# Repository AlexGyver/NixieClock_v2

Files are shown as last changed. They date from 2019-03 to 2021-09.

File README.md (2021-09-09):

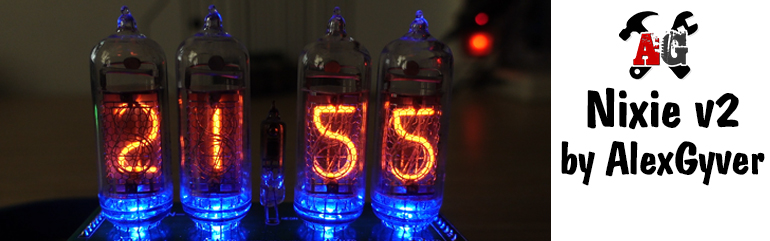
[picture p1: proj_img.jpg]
PROJECT_PHOTO

# Часы на газоразрядных индикаторах и Arduino
* [Описание проекта](#chapter-0)
* [Папки проекта](#chapter-1)
* [Схемы подключения](#chapter-2)
* [Материалы и компоненты](#chapter-3)
* [Как скачать и прошить](#chapter-4)
* [FAQ](#chapter-5)
* [Полезная информация](#chapter-6)
AlexGyver YouTube (https://www.youtube.com/channel/UCgtAOyEQdAyjvm9ATCi_Aig?sub_confirmation=1)

## Описание проекта
Часы на советских газоразрядных индикаторах под управлением платформы Arduino, версия 2. 
Страница проекта на сайте: https://alexgyver.ru/nixieclock_v2/

Решил я сделать максимально простой и доступный проект часов на газоразрядных индикаторах и Arduino! Односторонняя плата, выводные компоненты, никакой жести!

Платы:
- Габариты платы меньше 100х100мм, то есть заказать 10 таких плат у китайцев будет стоить $2 без учёта доставки
- Плата односторонняя, её без проблем можно сделать классическим ЛУТом!
- Все компоненты – выводные, припаяет даже новичок
- Количество компонентов сведено к минимуму!
- На данный момент в проекте есть платы под индикаторы ИН-12 и ИН-14, возможно будут сделаны и другие
- Система состоит из двух плат: нижней (вся управляющая электроника) и верхней (лампы и светодиоды подсветки)
- Нижних плат два варианта: обычная (4 оптопары, точка – светодиод) и с дополнительной оптопарой под неоновую точку (5 оптопар, точка – неонка)
- У плат ИН-14, ИН-12, ИН-12_перевертыш нижняя часть одинаковая! Части плат взаимозаменяемы. Нижняя плата отличается только у ИН-14_неон  

Хардварные фишки:
- Сердце платы – полноразмерная Arduino NANO, это означает простую сборку и прошивку
- Питание всей схемы – 5 Вольт
- Генератор высокого напряжения раскачивается ШИМ каналом Arduino
- Напряжение генератора подстраивается резистором с крутилкой
- Время задаёт RTC DS3231
- 3 кнопки для настройки времени и будильника
- Пищалка для будильника
- Подсветка ламп индикаторов
- Проект основан на плате Железнякова Андрея. Спасибо! Ссылка на проект: https://goo.gl/xTVQWP  

Софтварные фишки:
- “Перебор” цифр, не дающий индикаторам окисляться
- Режим будильника
- Плавное изменение яркости точки и подсветки (эффект “дыхания”)
	+ Расширенные настройки плавности дыхания
- Настройка яркости цифр, “точки” и подсветки ламп
	+ Два режима яркости от времени суток
- Разные режимы переключения индикаторов
	+ Плавное угасание/разгарание
	+ Перебор цифр
	+ Перебор катодов

## Папки
**ВНИМАНИЕ! Если это твой первый опыт работы с Arduino, читай [инструкцию](#chapter-4)**
- **libraries** - библиотеки проекта. Заменить имеющиеся версии (в этом проекте внешних библиотек нет)
- **firmware** - прошивки для Arduino
- **schemes** - схемы подключения компонентов

## Схемы
Платы:
- IN-14 - для индикаторов ИН-14 со светодиодной точкой https://easyeda.com/editor#id=1d7c359f88254c9d9c7ce9de914bd4c5
- IN-14_mini_neon_dot - для IN-14 с точкой - индикатором (+1 оптопара и резистор) https://easyeda.com/editor#id=be6c3cd8d42a414b8a8e5b9bdd0401bf
- IN-12 - для IN-12, цифры перевёрнуты вверх ногами (если смотреть на плату) https://easyeda.com/editor#id=1d7c359f88254c9d9c7ce9de914bd4c5
- IN-12_turned - для IN-12, цифры повёрнуты правильно https://easyeda.com/editor#id=aea22745380847b5beeca679820e7565  

Открыв плату по ссылке, её можно экспортировать в PDF, PNG или Altium (иконка папки слева сверху/экспорт) для изготовления ЛУТом или другими способами!  
При заказе плат у китайцев не забудьте указать в комментарии "Please make V-cut along middle thick horizontal outline" для надреза платы по средней линии  
**Гербер файлы уже есть в архиве!**
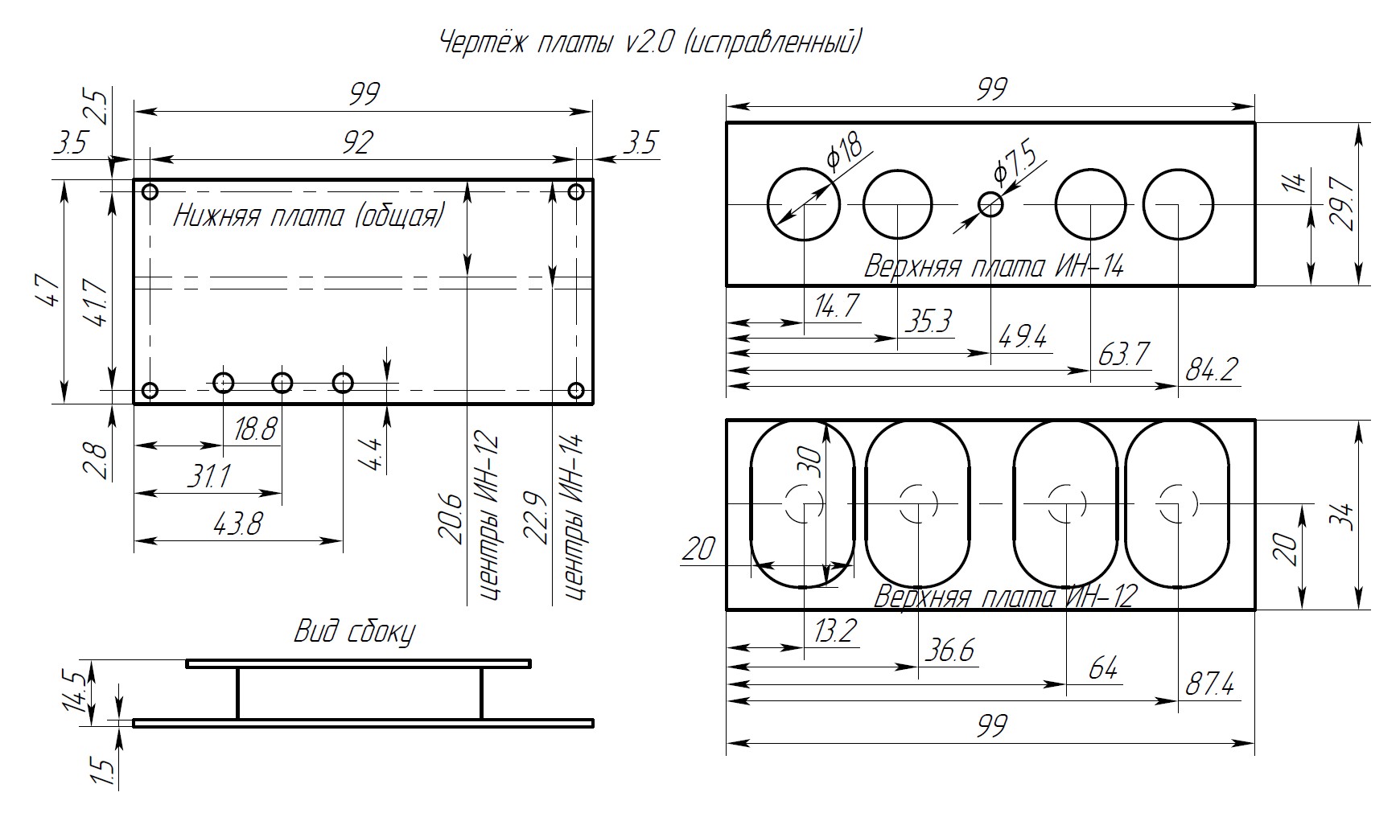
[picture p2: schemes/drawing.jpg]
SCHEME


## Материалы и компоненты
### Ссылки оставлены на магазины, с которых я закупаюсь уже не один год
- Arduino NANO Rev3.0 https://ali.ski/670JrC  https://ali.ski/_7IUJ
- RTC DS3231 https://ali.ski/gOYYG0
- Пищалка https://ali.ski/8LEYlE
- Гнёзда на плату https://www.chipdip.ru/product/pbs-40
- Рейка штыревая https://www.chipdip.ru/product/pls-40
- Конденсатор электролитический 4,7 мкФ 350V	https://www.chipdip.ru/product0/33635
- Резистор подстроечный 470 кОм (можно 500 кОм)	https://www.chipdip.ru/product/3362p-1-504
- Индуктивность 220 мкГн (uH)	https://www.chipdip.ru/product/ec24-221k
- Диод HER106	https://www.chipdip.ru/product/her106
- Транзистор IRF840PBF	https://www.chipdip.ru/product/irf840
- Оптопара TLP627(F) DIP-4	https://www.chipdip.ru/product/tlp627
- Дешифратор К155ИД1	https://www.chipdip.ru/product/k155id1
- Резисторы 0,25 Вт для версии ИН12/ИН14 со светодиодной точкой
	- 150 Ом
	- 470 Ом
	- 10 кОм	
	- 100 Ом - 3шт	
- Резисторы 0,25 Вт для версии ИН14 с неоновой точкой
	- 200 кОм
	- 470 Ом
	- 10 кОм	
	- 100 Ом - 3шт

## Вам скорее всего пригодится
* [Всё для пайки (паяльники и примочки)](http://alexgyver.ru/all-for-soldering/)
* [Недорогие инструменты](http://alexgyver.ru/my_instruments/)
* [Все существующие модули и сенсоры Arduino](http://alexgyver.ru/arduino_shop/)
* [Электронные компоненты](http://alexgyver.ru/electronics/)
* [Аккумуляторы и зарядные модули](http://alexgyver.ru/18650/)

## Как скачать и прошить
* [Первые шаги с Arduino](http://alexgyver.ru/arduino-first/) - ультра подробная статья по началу работы с Ардуино, ознакомиться первым делом!
* Скачать архив с проектом
> На главной странице проекта (где ты читаешь этот текст) вверху справа зелёная кнопка **Clone or download**, вот её жми, там будет **Download ZIP**
* Установить библиотеки в  
`C:\Program Files (x86)\Arduino\libraries\` (Windows x64)  
`C:\Program Files\Arduino\libraries\` (Windows x86)
* **Подключить внешнее питание 5 Вольт**
* Подключить Ардуино к компьютеру
* Запустить файл прошивки (который имеет расширение .ino)
* Настроить IDE (COM порт, модель Arduino, как в статье выше)
* Настроить что нужно по проекту
* Нажать загрузить
* Пользоваться  

## Настройки в коде

## FAQ
### Основные вопросы
В: Как скачать с этого грёбаного сайта?  
О: На главной странице проекта (где ты читаешь этот текст) вверху справа зелёная кнопка **Clone or download**, вот её жми, там будет **Download ZIP**

В: Скачался какой то файл .zip, куда его теперь?  
О: Это архив. Можно открыть стандартными средствами Windows, но думаю у всех на компьютере установлен WinRAR, архив нужно правой кнопкой и извлечь.

В: Я совсем новичок! Что мне делать с Ардуиной, где взять все программы?  
О: Читай и смотри видос http://alexgyver.ru/arduino-first/

В: Вылетает ошибка загрузки / компиляции!
О: Читай тут: https://alexgyver.ru/arduino-first/#step-5

В: Сколько стоит?  
О: Ничего не продаю.

### Вопросы по этому проекту

## Полезная информация
* [Мой сайт](http://alexgyver.ru/)
* [Основной YouTube канал](https://www.youtube.com/channel/UCgtAOyEQdAyjvm9ATCi_Aig?sub_confirmation=1)
* [YouTube канал про Arduino](https://www.youtube.com/channel/UC4axiS76D784-ofoTdo5zOA?sub_confirmation=1)
* [Мои видеоуроки по пайке](https://www.youtube.com/playlist?list=PLOT_HeyBraBuMIwfSYu7kCKXxQGsUKcqR)
* [Мои видеоуроки по Arduino](http://alexgyver.ru/arduino_lessons/)

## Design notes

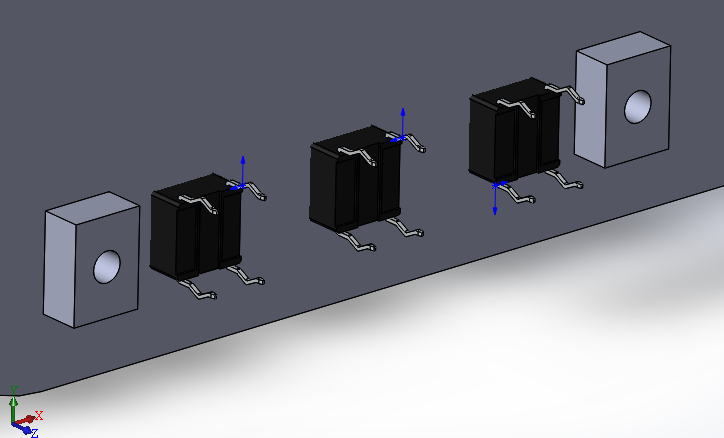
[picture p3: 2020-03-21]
case/IN-12_Max/Кнопки1.png

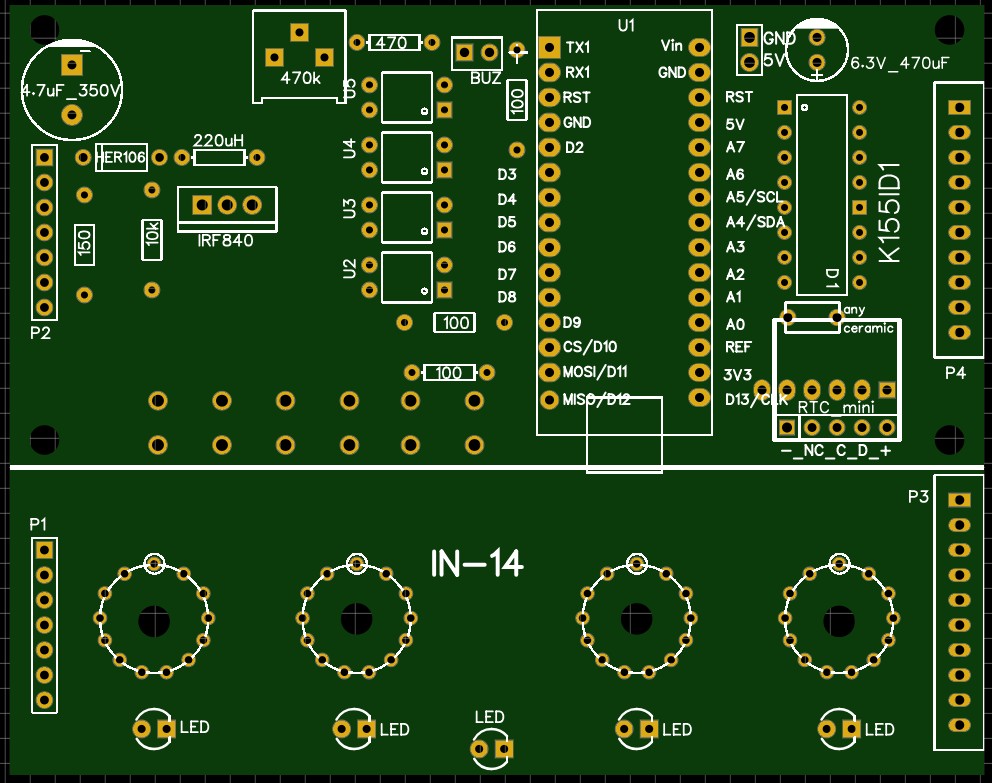
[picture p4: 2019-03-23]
schemes/IN-14.jpg

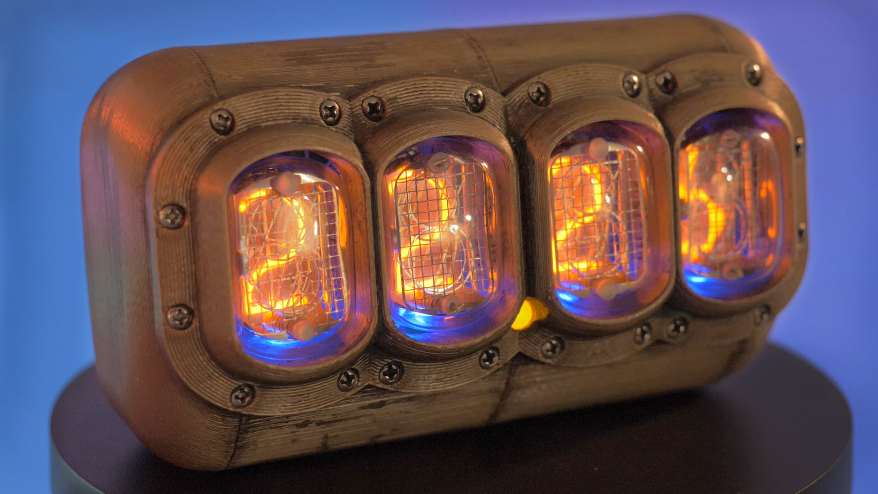
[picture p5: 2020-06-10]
case/IN-12_Gyver/photo.jpg

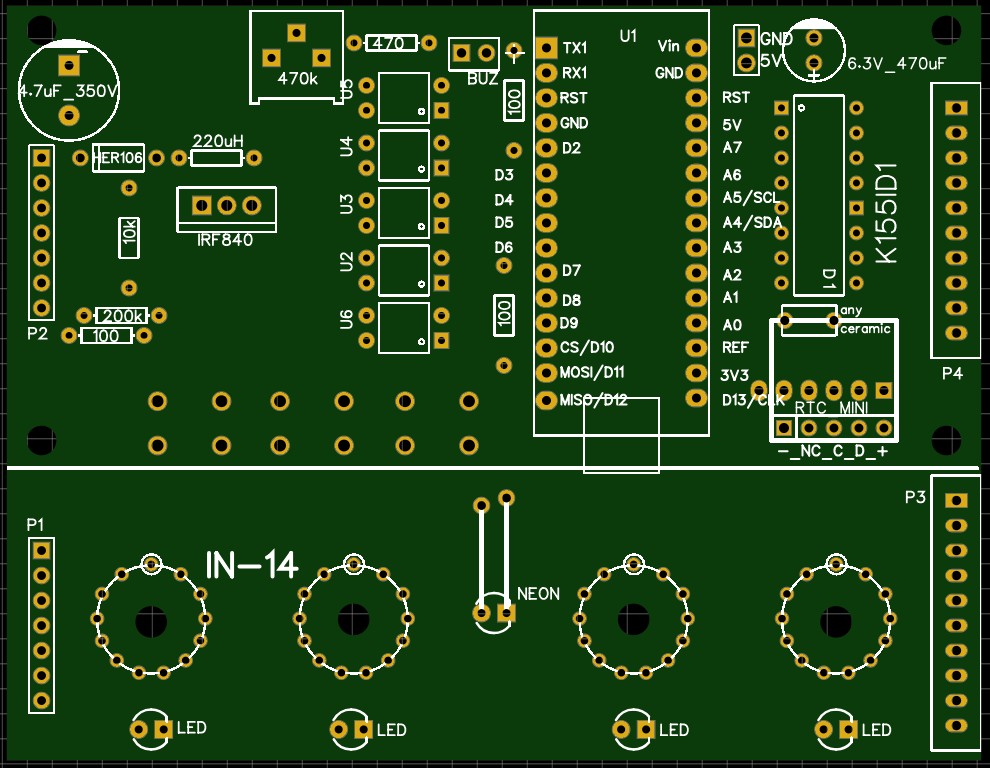
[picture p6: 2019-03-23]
schemes/IN-14_NEON.jpg

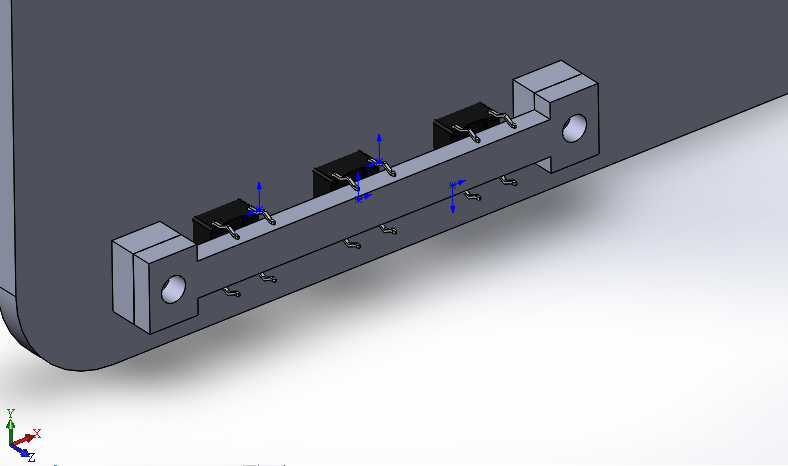
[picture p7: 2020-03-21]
case/IN-12_Max/Кнопки2.png

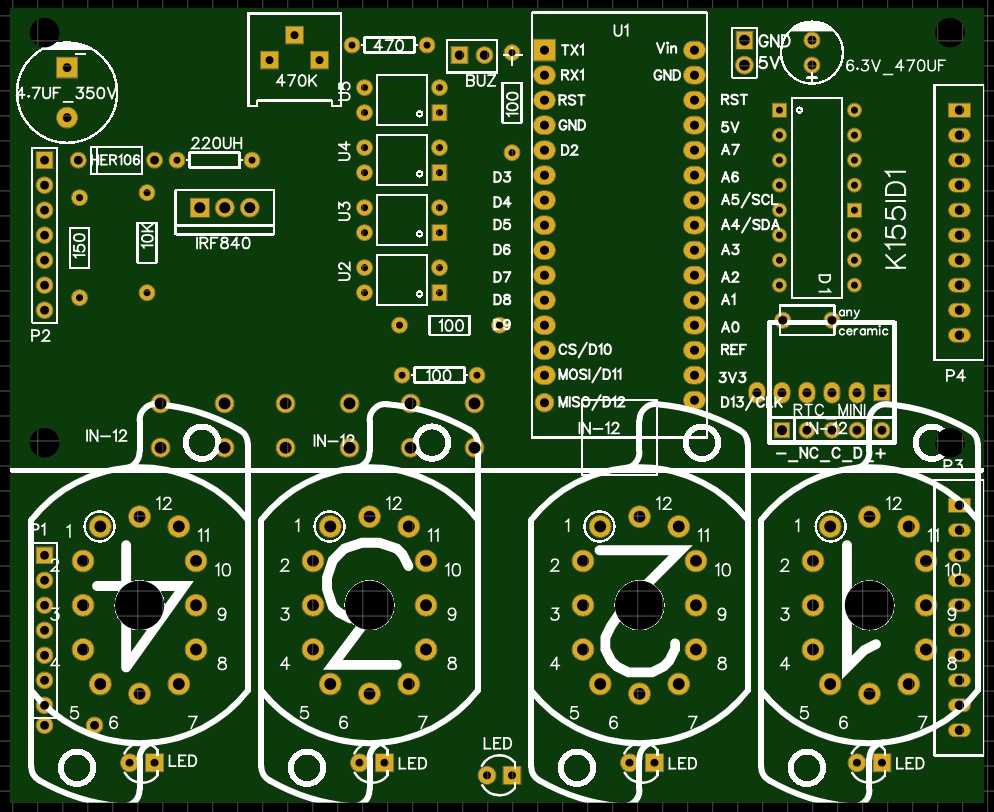
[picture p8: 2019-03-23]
schemes/IN-12.jpg

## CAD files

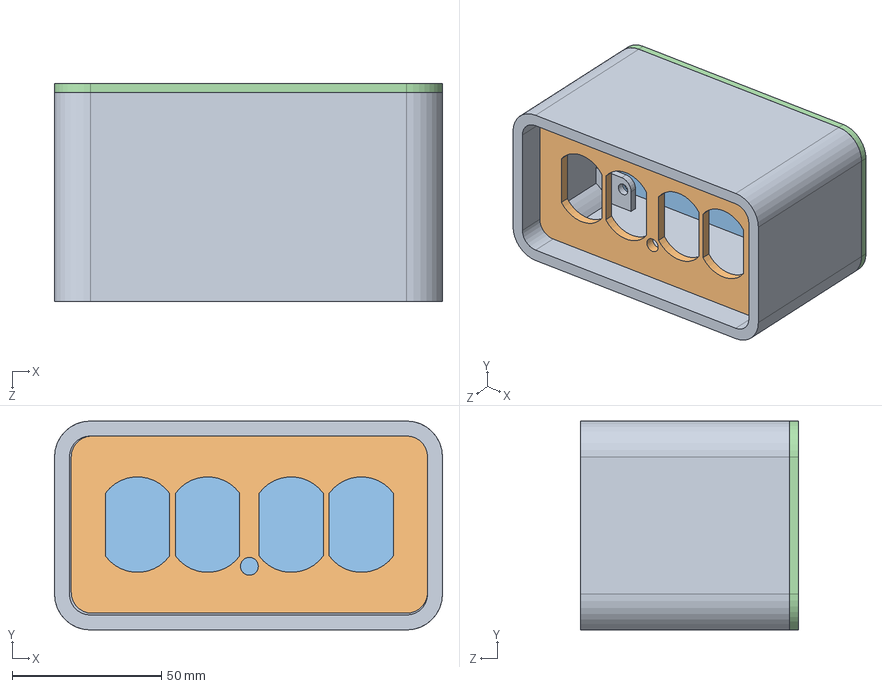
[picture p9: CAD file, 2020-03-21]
case/IN-12_Max/Исходники/Сборка ГРИ.SLDASM
130.0 x 70.0 x 73.0 mm
корпус
панель
плата
крышка
крепление кнопок

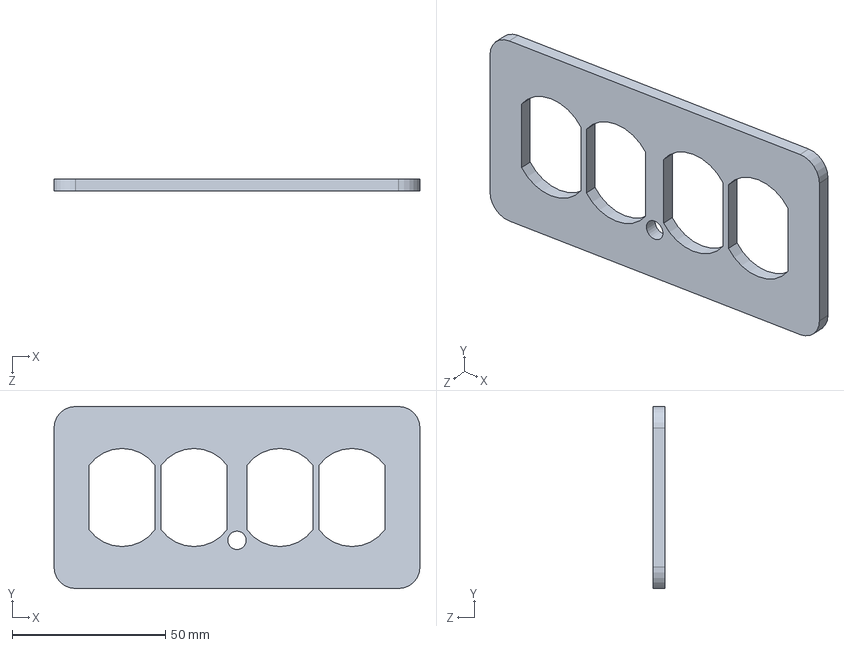
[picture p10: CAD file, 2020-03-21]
case/IN-12_Max/Исходники/панель.SLDPRT
119.4 x 59.4 x 4.00 mm

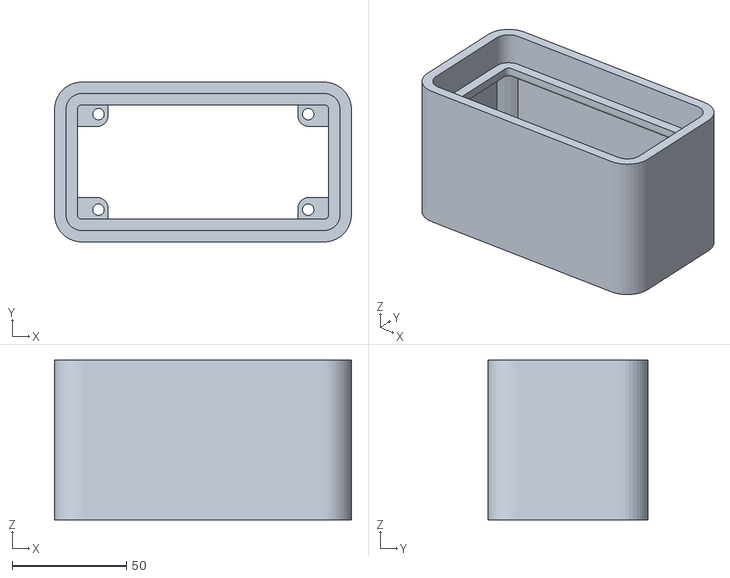
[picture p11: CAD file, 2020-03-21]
case/IN-12_Max/Файлы для печати/корпус.STL
130.0 x 70.0 x 70.0

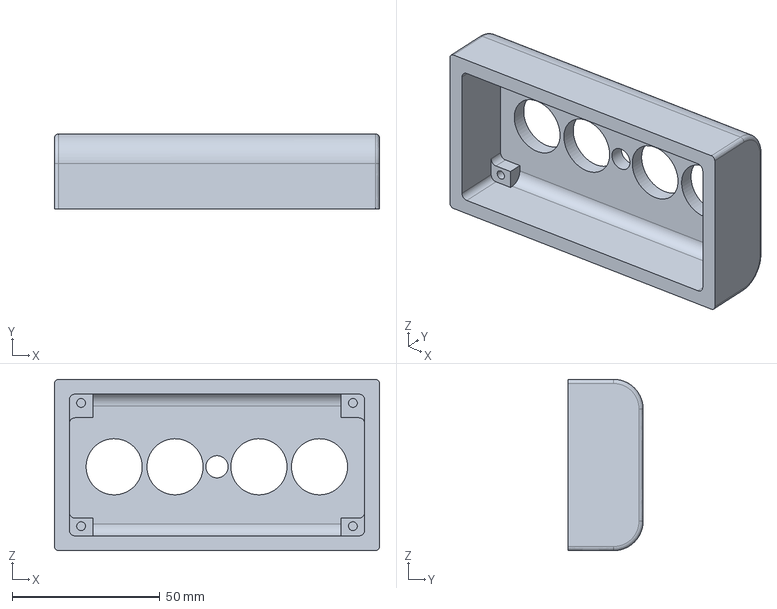
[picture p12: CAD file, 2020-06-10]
case/IN-14_Gyver/step/body.step
110.0 x 25.5 x 58.0 mm

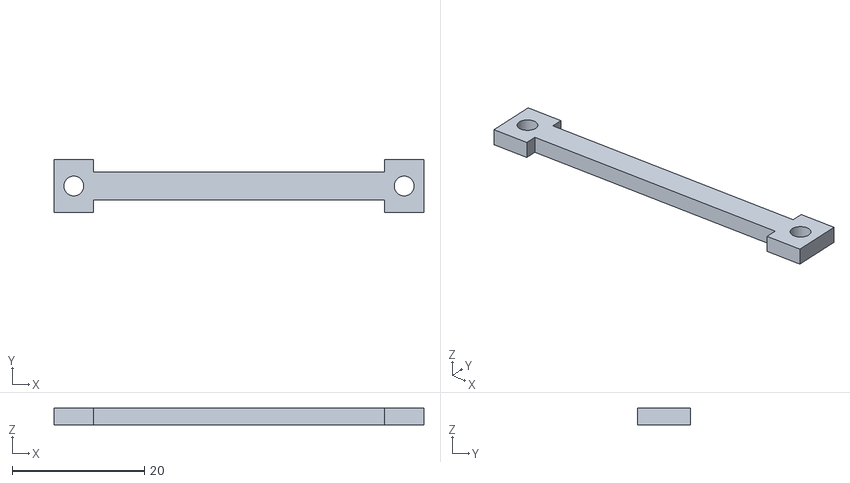
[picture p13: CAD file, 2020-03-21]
case/IN-12_Max/Файлы для печати/крепление кнопок.STL
56.0 x 8.00 x 2.50

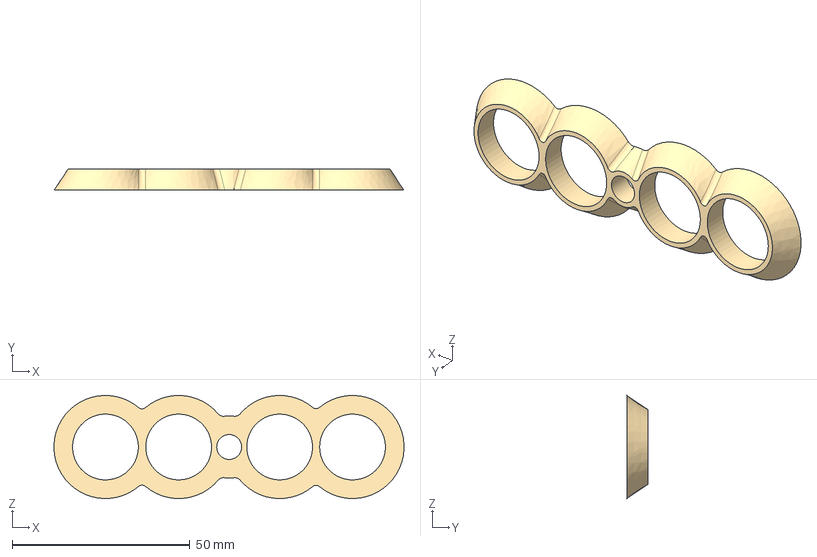
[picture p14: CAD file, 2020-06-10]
case/IN-14_Gyver/step/shield.step
98.4 x 6.00 x 29.0 mm

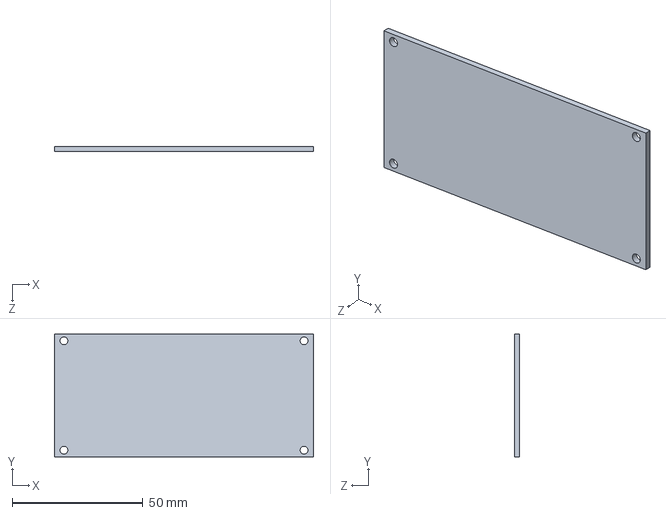
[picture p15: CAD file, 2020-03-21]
case/IN-12_Max/Исходники/плата.SLDPRT
99.0 x 47.0 x 2.00 mm

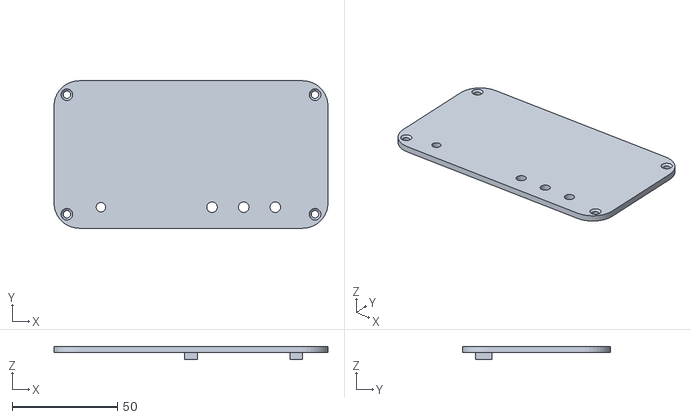
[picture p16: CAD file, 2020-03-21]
case/IN-12_Max/Файлы для печати/крышка.STL
130.0 x 70.0 x 6.40

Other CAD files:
case/IN-12_Max/Файлы для печати/панель.STL
case/IN-12_Max/Исходники/крепление кнопок.SLDPRT
case/IN-12_Max/Исходники/крышка.SLDPRT
case/IN-12_Max/Исходники/корпус.SLDPRT
case/IN-14_Gyver/fusion project.f3d
case/IN-14_Gyver/stl/body.stl
case/IN-14_Gyver/stl/shield.stl

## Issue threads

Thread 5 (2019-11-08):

гамма-коррекция точки

x3mEr, 2019-11-08:
Привет. Спасибо за проект и особенно за "глюки". Повторил часы только из-за него)
В версии 1.6 ты применяешь гамма-коррекцию и к точке, но если точка - неонка, применять не надо.

AlexGyver, 2019-11-10:
Привет, почему?)

x3mEr, 2019-11-12:
Не мог раньше ответить.
Хороший вопрос)) Действительно, почему...
Я перепутал. Почему-то думал, что для неонки яркость другая.
Ну, во всяком случае, надо снимать яркость неонки при различном ШИМе, строить график, аппроксимировать функцию, и выдавать значения по функции. Но это уже перебор)
Твоя чистая версия 1.6 почему-то не работает у меня с неонкой - точно светит очень-очень тускло.

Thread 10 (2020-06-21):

Перевернутые ИН-12А

maniak26, 2020-06-21:
Для перевернутых индикаторов ИН-12а правльная маска дешифратора:

byte digitMask[] = {9, 8, 0, 5, 2, 7, 3, 6, 4, 1}; // маска дешифратора платы in12a (цифры вверх ногами)

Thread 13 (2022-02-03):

Нехилый Баг в скетче buttonsSettings.ino

SergejBre, 2022-02-03:
Нашел в прошивке nixieClock_2_v2.5 ошибку. Столкнулся с багом, когда переходил на зимнее время. Перевел часы на час назад, но поменялось не только время, но и дата! Откатило аш на 2 года назад (2019, 12, 05)

Поправь скетч [buttonsSettings.ino](https://github.com/AlexGyver/NixieClock_v2/blob/master/firmware/nixieClock_2_v2.5/buttonsSettings.ino) на странице проекта. В секции buttonsSettings замени строку:

`rtc.adjust(DateTime(2019, 12, 05, hrs, mins, 0));`

на

```
{
  DateTime now = rtc.now();
  rtc.adjust( DateTime( now.year(), now.month(), now.day(), hrs, mins, 0 ));
}
```
Блок нужен, чтобы компилятор не ругался)).

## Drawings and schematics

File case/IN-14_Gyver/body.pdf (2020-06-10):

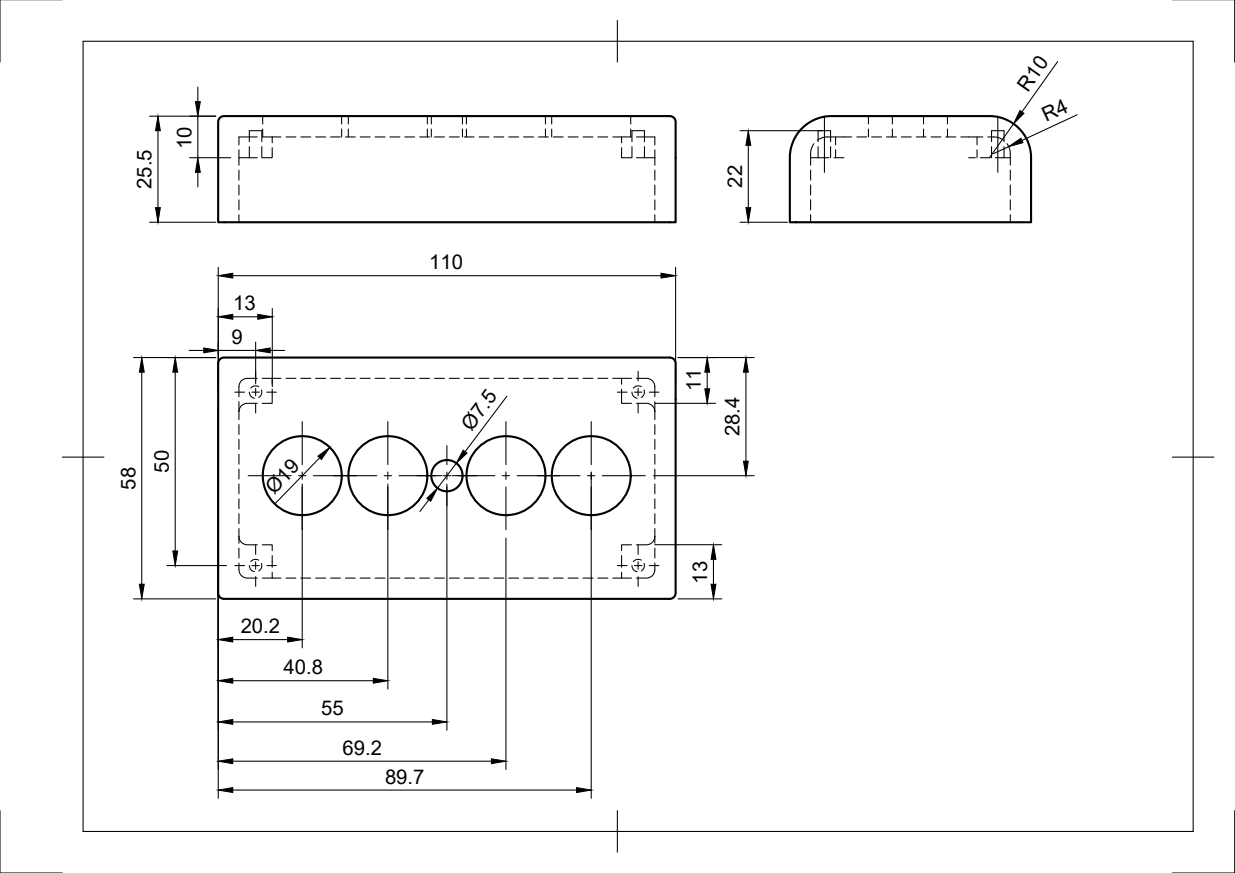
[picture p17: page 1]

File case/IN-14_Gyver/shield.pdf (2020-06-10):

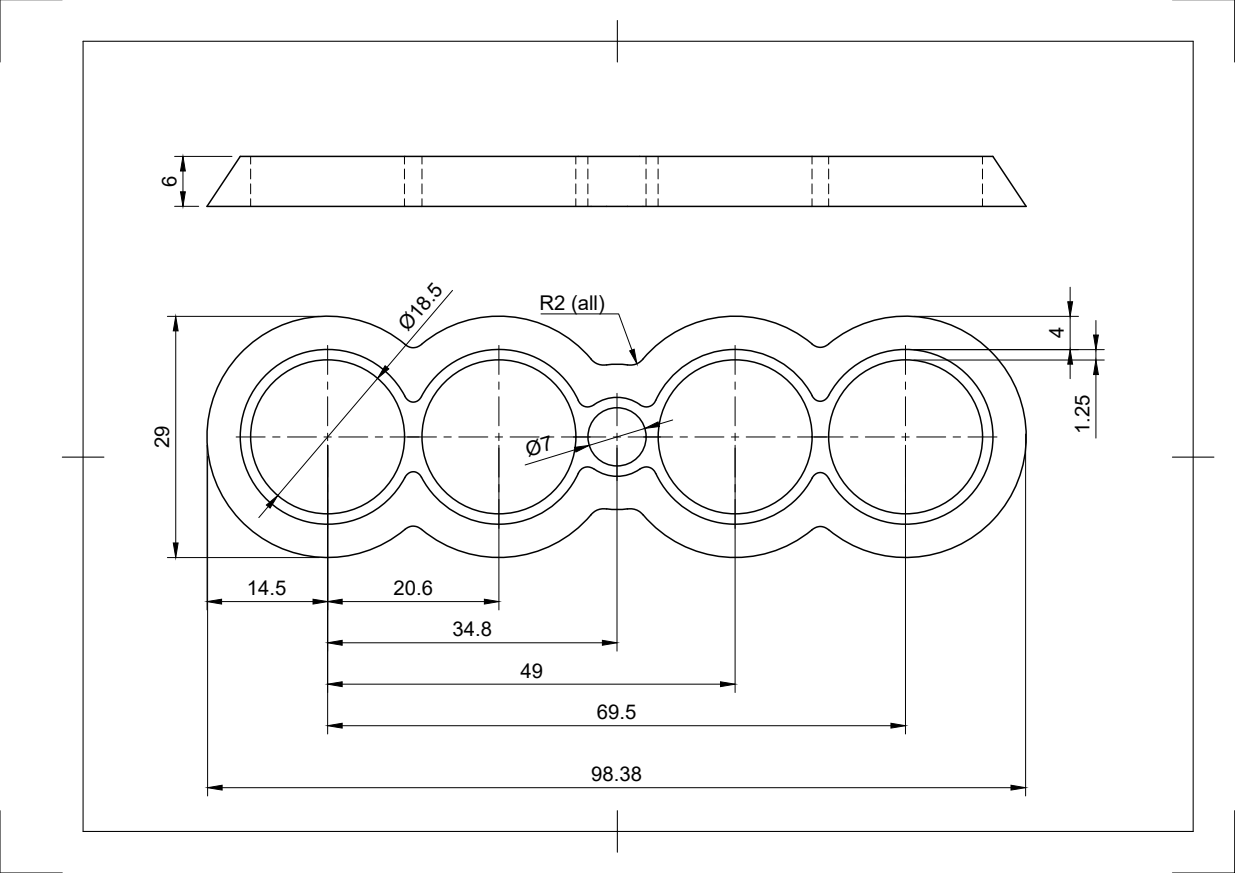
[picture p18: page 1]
Ø18.5 4 291.25 R2 (all)

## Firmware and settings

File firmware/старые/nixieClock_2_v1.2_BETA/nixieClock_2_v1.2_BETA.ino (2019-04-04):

/*
  Скетч к проекту "Часы на ГРИ версия 2"
  Страница проекта (схемы, описания): https://alexgyver.ru/nixieclock_v2/
  Исходники на GitHub: https://github.com/AlexGyver/NixieClock_v2
  Нравится, как написан код? Поддержи автора! https://alexgyver.ru/support_alex/
  Автор: AlexGyver Technologies, 2018
  https://AlexGyver.ru/
*/
/*
   Отличия от 1.1:
   - Чуть переделан блок кода, отвечающий за распиновку ламп
*/

// ************************** НАСТРОЙКИ **************************
#define BOARD_TYPE 0
// тип платы часов:
// 0 - IN-12 turned (индикаторы стоят правильно)
// 1 - IN-12 (индикаторы перевёрнуты)
// 2 - IN-14 (обычная и neon dot)
// 3 другие индикаторы

#define FLIP_EFFECT 1
// эффекты перелистывания часов:
// 0 - нет эффекта
// 1 - плавное угасание и появление (рекомендуемая скорость: 100-150)
// 2 - перемотка по порядку числа (рекомендуемая скорость: 50-80)
// 3 - перемотка по порядку катодов в лампе (рекомендуемая скорость: 30-50)

#define FLIP_SPEED 40       // скорость эффекта, мс

// -------- яркость --------
#define NIGHT_LIGHT 1       // менять яркость от времени суток (1 вкл, 0 выкл)
#define NIGHT_START 23      // час перехода на ночную подсветку (BRIGHT_N)
#define NIGHT_END 7         // час перехода на дневную подсветку (BRIGHT)

#define INDI_BRIGHT 23      // яркость цифр дневная (0 - 24) !на 24 могут быть фантомные цифры!
#define INDI_BRIGHT_N 3     // яркость ночная (0 - 24)

#define DOT_BRIGHT 10       // яркость точки дневная (0 - 255)
#define DOT_BRIGHT_N 3      // яркость точки ночная (0 - 255)

#define BACKL_BRIGHT 180    // яркость подсветки ламп дневная (0 - 255)
#define BACKL_BRIGHT_N 20   // яркость подсветки ламп ночная (0 - 255)
#define BACKL_PAUSE 1000    // пазуа "темноты" между вспышками подсветки, мс

// -------- глюки --------
#define GLITCH_ALLOWED 1    // 1 - включить, 0 - выключить глюки
#define GLITCH_MIN 30       // минимальное время между глюками, с
#define GLITCH_MAX 120      // максимальное время между глюками, с

// -------- мигание --------
#define DOT_TIME 500        // время мигания точки, мс
#define DOT_TIMER 20        // шаг яркости точки, мс

#define BACKL_STEP 2        // шаг мигания подсветки
#define BACKL_TIME 5000     // период подсветки, мс

// -------- будильник --------
#define ALM_TIMEOUT 30      // таймаут будильника
#define FREQ 900            // частота писка будильника

// --------- другое --------
#define BURN_TIME 1         // период обхода в режиме очистки, мс

// *********************** ДЛЯ РАЗРАБОТЧИКОВ ***********************
// пины
#define PIEZO 2   // пищалка
#define KEY0 3    // часы
#define KEY1 4    // часы 
#define KEY2 5    // минуты
#define KEY3 6    // минуты
#define BTN1 7    // кнопка 1
#define BTN2 8    // кнопка 2
#define GEN 9     // генератор
#define DOT 10    // точка
#define BACKL 11  // подсветка
#define BTN3 12   // кнопка 3

// дешифратор
#define DECODER0 A0
#define DECODER1 A1
#define DECODER2 A2
#define DECODER3 A3

// распиновка ламп
#if (BOARD_TYPE == 0)
byte digitMask[] = {7, 3, 6, 4, 1, 9, 8, 0, 5, 2};   // маска дешифратора платы in12_turned (цифры нормальные)
byte opts[] = {KEY0, KEY1, KEY2, KEY3};              // порядок индикаторов слева направо
byte cathodeMask[] = {1, 6, 2, 7, 5, 0, 4, 9, 8, 3}; // порядок катодов in12

#elif (BOARD_TYPE == 1)
byte digitMask[] = {2, 8, 1, 9, 6, 4, 3, 5, 0, 7};   // маска дешифратора платы in12 (цифры вверх ногами)
byte opts[] = {KEY3, KEY2, KEY1, KEY0};              // порядок индикаторов справа налево (для IN-12 turned) и ин-14
byte cathodeMask[] = {1, 6, 2, 7, 5, 0, 4, 9, 8, 3}; // порядок катодов in12

#elif (BOARD_TYPE == 2)
byte digitMask[] = {9, 8, 0, 5, 4, 7, 3, 6, 2, 1};   // маска дешифратора платы in14
byte opts[] = {KEY3, KEY2, KEY1, KEY0};              // порядок индикаторов справа налево (для IN-12 turned) и ин-14
byte cathodeMask[] = {1, 0, 2, 9, 3, 8, 4, 7, 5, 6}; // порядок катодов in14

#elif (BOARD_TYPE == 3)
byte digitMask[] = {0, 1, 2, 3, 4, 5, 6, 7, 8, 9};   // тут вводим свой порядок пинов
byte opts[] = {KEY0, KEY1, KEY2, KEY3};              // свой порядок индикаторов
byte cathodeMask[] = {0, 1, 2, 3, 4, 5, 6, 7, 8, 9}; // и свой порядок катодов

#endif

// библиотеки
#include "GyverHacks.h"
#include "GyverTimer.h"
#include "GyverButton.h"
#include <Wire.h>
#include "RTClib.h"
#include "EEPROMex.h"
RTC_DS3231 rtc;

// таймеры
GTimer_ms dotTimer(500);                // полсекундный таймер для часов
GTimer_ms dotBrightTimer(DOT_TIMER);    // таймер шага яркости точки
GTimer_ms backlBrightTimer(30);         // таймер шага яркости подсветки
GTimer_ms almTimer((long)ALM_TIMEOUT * 1000);
GTimer_ms flipTimer(FLIP_SPEED);
GTimer_ms glitchTimer(1000);

// переменные
volatile int8_t indiDimm[4];      // величина диммирования (0-24)
volatile int8_t indiCounter[4];   // счётчик каждого индикатора (0-24)
volatile int8_t indiDigits[4];    // цифры, которые должны показать индикаторы (0-10)
volatile int8_t curIndi;          // текущий индикатор (0-3)

boolean dotFlag;
int8_t hrs, mins, secs;
int8_t alm_hrs, alm_mins;
int8_t mode = 0;    // 0 часы, 1 температура, 2 настройка будильника, 3 настройка часов, 4 аларм
boolean changeFlag;
boolean blinkFlag;
byte indiMaxBright = INDI_BRIGHT, dotMaxBright = DOT_BRIGHT, backlMaxBright = BACKL_BRIGHT;
boolean alm_flag;
boolean dotBrightFlag, dotBrightDirection, backlBrightFlag, backlBrightDirection, indiBrightDirection;
int dotBrightCounter, backlBrightCounter, indiBrightCounter;
byte dotBrightStep;
boolean newTimeFlag;
boolean flipIndics[4];
byte newTime[4];
boolean flipInit;
byte startCathode[4], endCathode[4];
byte glitchCounter, glitchMax, glitchIndic;
boolean glitchFlag, indiState;

void setDig(byte digit) {
  digit = digitMask[digit];
  setPin(DECODER3, bitRead(digit, 0));
  setPin(DECODER1, bitRead(digit, 1));
  setPin(DECODER0, bitRead(digit, 2));
  setPin(DECODER2, bitRead(digit, 3));
}

void setup() {
  Serial.begin(9600);
  randomSeed(analogRead(6) + analogRead(7));

  // настройка пинов на выход
  pinMode(DECODER0, OUTPUT);
  pinMode(DECODER1, OUTPUT);
  pinMode(DECODER2, OUTPUT);
  pinMode(DECODER3, OUTPUT);
  pinMode(KEY0, OUTPUT);
  pinMode(KEY1, OUTPUT);
  pinMode(KEY2, OUTPUT);
  pinMode(KEY3, OUTPUT);
  pinMode(PIEZO, OUTPUT);
  pinMode(GEN, OUTPUT);
  pinMode(DOT, OUTPUT);
  pinMode(BACKL, OUTPUT);

  // задаем частоту ШИМ на 9 и 10 выводах 31 кГц
  TCCR1B = TCCR1B & 0b11111000 | 1;		// ставим делитель 1

  // включаем ШИМ
  // от скважности зависит напряжение! у 175 вольт при значении 180 и 145 вольт при 120
  setPWM(9, 180);

  // перенастраиваем частоту ШИМ на пинах 3 и 11 на 7.8 кГц и разрешаем прерывания COMPA
  TCCR2B = (TCCR2B & B11111000) | 2;    // делитель 8
  TCCR2A |= (1 << WGM21);   // включить CTC режим для COMPA
  TIMSK2 |= (1 << OCIE2A);  // включить прерывания по совпадению COMPA

  // ---- RTC ----
  rtc.begin();
  if (rtc.lostPower()) {
    rtc.adjust(DateTime(F(__DATE__), F(__TIME__)));
  }
  DateTime now = rtc.now();
  secs = now.second();
  mins = now.minute();
  hrs = now.hour();

  if (EEPROM.readByte(100) != 66) {   // проверка на первый запуск. 66 от балды
    EEPROM.writeByte(100, 66);
    EEPROM.writeByte(0, 0);     // часы будильника
    EEPROM.writeByte(1, 0);     // минуты будильника
  }
  alm_hrs = EEPROM.readByte(0);
  alm_mins = EEPROM.readByte(1);

  sendTime();         // отправить время на индикаторы
  changeBright();     // изменить яркость согласно времени суток

  for (byte i = 0; i < 4; i++)
    indiDimm[i] = indiMaxBright;

  dotBrightStep = ceil((float)dotMaxBright * 2 / DOT_TIME * DOT_TIMER);
  if (dotBrightStep == 0) dotBrightStep = 1;

  backlBrightTimer.setInterval((float)BACKL_STEP / backlMaxBright / 2 * BACKL_TIME);

  almTimer.stop();
  glitchTimer.setInterval(random(GLITCH_MIN * 1000L, GLITCH_MAX * 1000L));
  indiBrightCounter = indiMaxBright;
}

// динамическая индикация в прерывании таймера 2
ISR(TIMER2_COMPA_vect) {
  indiCounter[curIndi]++;             // счётчик индикатора
  if (indiCounter[curIndi] == indiDimm[curIndi])  // если достигли порога диммирования
    setPin(opts[curIndi], 0);         // выключить текущий индикатор

  if (indiCounter[curIndi] > 25) {    // достигли порога в 25 единиц
    indiCounter[curIndi] = 0;         // сброс счетчика лампы
    if (++curIndi >= 4) curIndi = 0;  // смена лампы закольцованная

    // отправить цифру из массива indiDigits согласно типу лампы
    if (indiDimm[curIndi] > 0) {
      byte thisDig = digitMask[indiDigits[curIndi]];
      setPin(DECODER3, bitRead(thisDig, 0));
      setPin(DECODER1, bitRead(thisDig, 1));
      setPin(DECODER0, bitRead(thisDig, 2));
      setPin(DECODER2, bitRead(thisDig, 3));
      setPin(opts[curIndi], 1);         // включить анод на текущую лампу
    }
  }
}

void loop() {
  if (dotTimer.isReady()) calculateTime();  // каждые 500 мс пересчёт и отправка времени
  if (newTimeFlag) flipTick();              // перелистывание цифр
  dotBrightTick();                          // плавное мигание точки
  backlBrightTick();                        // плавное мигание подсветки ламп
  glitchTick();
  //buttonsTick();
}

void glitchTick() {
#if (GLITCH_ALLOWED == 1)
  if (!glitchFlag && secs > 7 && secs < 55) {
    if (glitchTimer.isReady()) {
      glitchFlag = true;
      indiState = 0;
      glitchCounter = 0;
      glitchMax = random(2, 6);
      glitchIndic = random(0, 4);
      glitchTimer.setInterval(random(1, 6) * 40);
    }
  } else if (glitchFlag && glitchTimer.isReady()) {
    indiDimm[glitchIndic] = indiState * indiMaxBright;
    indiState = !indiState;
    glitchTimer.setInterval(random(1, 6) * 40);
    glitchCounter++;
    if (glitchCounter > glitchMax) {
      glitchTimer.setInterval(random(GLITCH_MIN * 1000L, GLITCH_MAX * 1000L));
      glitchFlag = false;
      indiDimm[glitchIndic] = indiMaxBright;
    }
  }
#endif
}

void flipTick() {
#if (FLIP_EFFECT == 0)
  sendTime();
  newTimeFlag = false;
#elif (FLIP_EFFECT == 1)
  if (!flipInit) {
    flipInit = true;
    // запоминаем, какие цифры поменялись и будем менять их яркость
    for (byte i = 0; i < 4; i++) {
      if (indiDigits[i] != newTime[i]) flipIndics[i] = true;
      else flipIndics[i] = false;
    }
  }

  if (flipTimer.isReady()) {
    if (!indiBrightDirection) {
      indiBrightCounter--;            // уменьшаем яркость
      if (indiBrightCounter <= 0) {   // если яроксть меньше нуля
        indiBrightDirection = true;   // меняем направление изменения
        indiBrightCounter = 0;        // обнуляем яркость
        sendTime();                   // меняем цифры
      }
    } else {
      indiBrightCounter++;                        // увеличиваем яркость
      if (indiBrightCounter >= indiMaxBright) {   // достигли предела
        indiBrightDirection = false;              // меняем направление
        indiBrightCounter = indiMaxBright;        // устанавливаем максимум
        // выходим из цикла изменения
        flipInit = false;
        newTimeFlag = false;
      }
    }
    for (byte i = 0; i < 4; i++)
      if (flipIndics[i]) indiDimm[i] = indiBrightCounter;   // применяем яркость
  }

#elif (FLIP_EFFECT == 2)
  if (!flipInit) {
    flipInit = true;
    // запоминаем, какие цифры поменялись и будем менять их
    for (byte i = 0; i < 4; i++) {
      if (indiDigits[i] != newTime[i]) flipIndics[i] = true;
      else flipIndics[i] = false;
    }
  }

  if (flipTimer.isReady()) {
    byte flipCounter = 0;
    for (byte i = 0; i < 4; i++) {
      if (flipIndics[i]) {
        indiDigits[i]--;
        if (indiDigits[i] < 0) indiDigits[i] = 9;
        if (indiDigits[i] == newTime[i]) flipIndics[i] = false;
      } else {
        flipCounter++;        // счётчик цифр, которые не надо менять
      }
    }
    if (flipCounter == 4) {   // если ни одну из 4 цифр менять не нужно
      // выходим из цикла изменения
      flipInit = false;
      newTimeFlag = false;
    }
  }

  //byte cathodeMask[] = {1, 0, 2, 9, 3, 8, 4, 7, 5, 6};  // порядок катодов in14
#elif (FLIP_EFFECT == 3)
  if (!flipInit) {
    flipInit = true;
    // запоминаем, какие цифры поменялись и будем менять их
    for (byte i = 0; i < 4; i++) {
      if (indiDigits[i] != newTime[i]) {
        flipIndics[i] = true;
        for (byte c = 0; c < 10; c++) {
          if (cathodeMask[c] == indiDigits[i]) startCathode[i] = c;
          if (cathodeMask[c] == newTime[i]) endCathode[i] = c;
        }
      }
      else flipIndics[i] = false;
    }
  }

  if (flipTimer.isReady()) {
    byte flipCounter = 0;
    for (byte i = 0; i < 4; i++) {
      if (flipIndics[i]) {
        if (startCathode[i] > endCathode[i]) {
          startCathode[i]--;
          indiDigits[i] = cathodeMask[startCathode[i]];
        } else if (startCathode[i] < endCathode[i]) {
          startCathode[i]++;
          indiDigits[i] = cathodeMask[startCathode[i]];
        } else {
          flipIndics[i] = false;
        }
      } else {
        flipCounter++;
      }
    }
    if (flipCounter == 4) {   // если ни одну из 4 цифр менять не нужно
      // выходим из цикла изменения
      flipInit = false;
      newTimeFlag = false;
    }
  }
#endif
}

void backlBrightTick() {
  if (backlBrightTimer.isReady()) {
    if (backlBrightDirection) {
      if (!backlBrightFlag) {
        backlBrightFlag = true;
        backlBrightTimer.setInterval((float)BACKL_STEP / backlMaxBright / 2 * BACKL_TIME);
      }
      backlBrightCounter += BACKL_STEP;
      if (backlBrightCounter >= backlMaxBright) {
        backlBrightDirection = false;
        backlBrightCounter = backlMaxBright;
      }
    } else {
      backlBrightCounter -= BACKL_STEP;
      if (backlBrightCounter <= 0) {
        backlBrightDirection = true;
        backlBrightCounter = 0;
        backlBrightTimer.setInterval(BACKL_PAUSE);
        backlBrightFlag = false;
      }
    }
    setPWM(BACKL, backlBrightCounter);
  }
}

void dotBrightTick() {
  if (dotBrightFlag && dotBrightTimer.isReady()) {
    if (dotBrightDirection) {
      dotBrightCounter += dotBrightStep;
      if (dotBrightCounter >= dotMaxBright) {
        dotBrightDirection = false;
        dotBrightCounter = dotMaxBright;
      }
    } else {
      dotBrightCounter -= dotBrightStep;
      if (dotBrightCounter <= 0) {
        dotBrightDirection = true;
        dotBrightFlag = false;
        dotBrightCounter = 0;
      }
    }
    setPWM(DOT, dotBrightCounter);
  }
}

void sendTime() {
  indiDigits[0] = (byte)hrs / 10;
  indiDigits[1] = (byte)hrs % 10;

  indiDigits[2] = (byte)mins / 10;
  indiDigits[3] = (byte)mins % 10;
}

void setNewTime() {
  newTime[0] = (byte)hrs / 10;
  newTime[1] = (byte)hrs % 10;

  newTime[2] = (byte)mins / 10;
  newTime[3] = (byte)mins % 10;
}

void changeBright() {
#if (NIGHT_LIGHT == 1)
  // установка яркости всех светилок от времени суток
  if ( (hrs >= NIGHT_START && hrs <= 23)
       || (hrs >= 0 && hrs <= NIGHT_END) ) {
    indiMaxBright = INDI_BRIGHT_N;
    dotMaxBright = DOT_BRIGHT_N;
    backlMaxBright = BACKL_BRIGHT_N;
  } else {
    indiMaxBright = INDI_BRIGHT;
    dotMaxBright = DOT_BRIGHT;
    backlMaxBright = BACKL_BRIGHT;
  }
  for (byte i = 0; i < 4; i++) {
    indiDimm[i] = indiMaxBright;
  }

  dotBrightStep = ceil((float)dotMaxBright * 2 / DOT_TIME * DOT_TIMER);
  if (dotBrightStep == 0) dotBrightStep = 1;

  backlBrightTimer.setInterval((float)BACKL_STEP / backlMaxBright / 2 * BACKL_TIME);
  indiBrightCounter = indiMaxBright;
#endif
}

void calculateTime() {
  dotFlag = !dotFlag;
  if (dotFlag) {
    dotBrightFlag = true;
    dotBrightDirection = true;
    dotBrightCounter = 0;
    secs++;
    if (secs > 59) {
      newTimeFlag = true;   // флаг что нужно поменять время
      secs = 0;
      mins++;

      if (mins == 1 || mins == 30) {    // каждые полчаса
        burnIndicators();               // чистим чистим!
        DateTime now = rtc.now();       // синхронизация с RTC
        secs = now.second();
        mins = now.minute();
        hrs = now.hour();
      }

      if (!alm_flag && alm_mins == mins && alm_hrs == hrs && true) {
        mode = 0;
        alm_flag = true;
        almTimer.start();
        almTimer.reset();
      }
    }
    if (mins > 59) {
      mins = 0;
      hrs++;
      if (hrs > 23) hrs = 0;
      changeBright();
    }
    if (newTimeFlag) setNewTime();         // обновляем массив времени

    /*
        if (mode == 0) sendTime();

        if (alm_flag) {
          if (almTimer.isReady() || true ) {
            alm_flag = false;
            almTimer.stop();
            mode = 0;
            noTone(PIEZO);
          }
        }
    */
  }

  /*
    // мигать на будильнике
    if (alm_flag) {
      if (!dotFlag) {
        noTone(PIEZO);
        for (byte i = 1; i < 7; i++) digitsDraw[i] = 10;
      } else {
        tone(PIEZO, FREQ);
        sendTime();
      }
    }
  */
}


void burnIndicators() {
  for (byte d = 0; d < 10; d++) {
    for (byte i = 0; i < 4; i++) {
      indiDigits[i]--;
      if (indiDigits[i] < 0) indiDigits[i] = 9;
    }
    delay(BURN_TIME);
  }
}

/*
  ард ног ном
  А0  7   4
  А1  6   2
  А2  4   8
  А3  3   1
*/

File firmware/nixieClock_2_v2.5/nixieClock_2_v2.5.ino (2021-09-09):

/*
  Скетч к проекту "Часы на ГРИ версия 2"
  Страница проекта (схемы, описания): https://alexgyver.ru/nixieclock_v2/
  Исходники на GitHub: https://github.com/AlexGyver/NixieClock_v2
  Нравится, как написан код? Поддержи автора! https://alexgyver.ru/support_alex/
  Автор: AlexGyver Technologies, 2018
  https://AlexGyver.ru/
*/

/*
  Управление:
  - Настройка времени:
    - Левая кнопка - выбор, остальные "больше" и "меньше"
    - Удержать "выбор" - настройка времени
    - Клик по "выбору" - смена настройки часы/минуты
    - Клик "больше" и "меньше" - изменение времени
    - Удержать "выбор" - возврат к режиму часов

  - Управление эффектами В РЕЖИМЕ ЧАСОВ:
    - Удержание центральной кнопки включает и выключает "глюки"
    - Клик по центральной кнопке переключает режимы подсветки ламп
      - Дыхание
      - Постоянное свечение
      - Отключена
    - Клик по правой кнопке переключает режимы перелистывания цифр
      - Без эффекта
      - Плавное угасание
      - Перемотка по порядку числа
      - Перемотка по катодам
      - Поезд
      - Резинка
*/
/*
  Версия 2.0 (совместно с Pavel Smelov):
  - Поправлены косяки с подсветкой
  - Добавлены эффекты переключения "поезд" и "резинка"
  - Оптимизирован код

  Версия 2.1:
  - Исправлена ошибка с ходом времени

  Версия 2.2:
  - Сброс секунд при установке времени
  
  Версия 2.3:
  - Добавлены расширенные настройки яркости
  - Исправлены зависания при нулевых значениях некоторых настроек

  Версия 2.4:
  - Продолжаем исправлять баги с нулевыми настройками

  Версия 2.6:
  - Демонстрация эффекта при выборе
*/

// ************************** НАСТРОЙКИ **************************
#define BOARD_TYPE 2
// тип платы часов:
// 0 - IN-12 turned (индикаторы стоят правильно)
// 1 - IN-12 (индикаторы перевёрнуты)
// 2 - IN-14 (обычная и neon dot)
// 3 другие индикаторы

#define DUTY 180        // скважность ШИМ. От скважности зависит напряжение! у меня 175 вольт при значении 180 и 145 вольт при 120

// ======================= ЭФФЕКТЫ =======================
// эффекты перелистывания часов
byte FLIP_EFFECT = 1;
// Выбранный активен при первом запуске и меняется кнопками. Запоминается в память
// 0 - нет эффекта
// 1 - плавное угасание и появление (рекомендуемая скорость: 100-150)
// 2 - перемотка по порядку числа (рекомендуемая скорость: 50-80)
// 3 - перемотка по порядку катодов в лампе (рекомендуемая скорость: 30-50)
// 4 - поезд (рекомендуемая скорость: 50-170)
// 5 - резинка (рекомендуемая скорость: 50-150)


// =======================  ЯРКОСТЬ =======================
#define NIGHT_LIGHT 1       // менять яркость от времени суток (1 вкл, 0 выкл)
#define NIGHT_START 23      // час перехода на ночную подсветку (BRIGHT_N)
#define NIGHT_END 7         // час перехода на дневную подсветку (BRIGHT)

#define INDI_BRIGHT 23      // яркость цифр дневная (1 - 24) !на 24 могут быть фантомные цифры!
#define INDI_BRIGHT_N 3     // яркость ночная (1 - 24)

#define DOT_BRIGHT 35       // яркость точки дневная (1 - 255)
#define DOT_BRIGHT_N 15     // яркость точки ночная (1 - 255)

#define BACKL_BRIGHT 250    // макс. яркость подсветки ламп дневная (0 - 255)
#define BACKL_BRIGHT_N 50   // макс. яркость подсветки ламп ночная (0 - 255, 0 - подсветка выключена)
#define BACKL_MIN_BRIGHT 20 // мин. яркость подсветки ламп в режиме дыхание (0 - 255)
#define BACKL_PAUSE 400     // пазуа "темноты" между вспышками подсветки ламп в режиме дыхание, мс

// =======================  ГЛЮКИ =======================
#define GLITCH_MIN 30       // минимальное время между глюками, с
#define GLITCH_MAX 120      // максимальное время между глюками, с

// ======================  МИГАНИЕ =======================
#define DOT_TIME 500        // время мигания точки, мс
#define DOT_TIMER 20        // шаг яркости точки, мс

#define BACKL_STEP 2        // шаг мигания подсветки
#define BACKL_TIME 5000     // период подсветки, мс

// ==================  АНТИОТРАВЛЕНИЕ ====================
#define BURN_TIME 10        // период обхода индикаторов в режиме очистки, мс
#define BURN_LOOPS 3        // количество циклов очистки за каждый период
#define BURN_PERIOD 15      // период антиотравления, минут


// *********************** ДЛЯ РАЗРАБОТЧИКОВ ***********************
byte BACKL_MODE = 0;                          // Выбранный активен при запуске и меняется кнопками
byte FLIP_SPEED[] = {0, 130, 50, 40, 70, 70}; // скорость эффектов, мс (количество не меняй)
byte FLIP_EFFECT_NUM = sizeof(FLIP_SPEED);    // количество эффектов
boolean GLITCH_ALLOWED = 1;                   // 1 - включить, 0 - выключить глюки. Управляется кнопкой

// --------- БУДИЛЬНИК ---------
#define ALM_TIMEOUT 30      // таймаут будильника
#define FREQ 900            // частота писка будильника

// пины
#define PIEZO 2   // пищалка
#define KEY0 3    // часы
#define KEY1 4    // часы 
#define KEY2 5    // минуты
#define KEY3 6    // минуты
#define BTN1 7    // кнопка 1
#define BTN2 8    // кнопка 2
#define GEN 9     // генератор
#define DOT 10    // точка
#define BACKL 11  // подсветка
#define BTN3 12   // кнопка 3

// дешифратор
#define DECODER0 A0
#define DECODER1 A1
#define DECODER2 A2
#define DECODER3 A3

// распиновка ламп
#if (BOARD_TYPE == 0)
const byte digitMask[] = {7, 3, 6, 4, 1, 9, 8, 0, 5, 2};   // маска дешифратора платы in12_turned (цифры нормальные)
const byte opts[] = {KEY0, KEY1, KEY2, KEY3};              // порядок индикаторов слева направо
const byte cathodeMask[] = {1, 6, 2, 7, 5, 0, 4, 9, 8, 3}; // порядок катодов in12

#elif (BOARD_TYPE == 1)
const byte digitMask[] = {2, 8, 1, 9, 6, 4, 3, 5, 0, 7};   // маска дешифратора платы in12 (цифры вверх ногами)
const byte opts[] = {KEY3, KEY2, KEY1, KEY0};              // порядок индикаторов справа налево (для IN-12 turned) и ин-14
const byte cathodeMask[] = {1, 6, 2, 7, 5, 0, 4, 9, 8, 3}; // порядок катодов in12

#elif (BOARD_TYPE == 2)
const byte digitMask[] = {9, 8, 0, 5, 4, 7, 3, 6, 2, 1};   // маска дешифратора платы in14
const byte opts[] = {KEY3, KEY2, KEY1, KEY0};              // порядок индикаторов справа налево (для IN-12 turned) и ин-14
const byte cathodeMask[] = {1, 0, 2, 9, 3, 8, 4, 7, 5, 6}; // порядок катодов in14

#elif (BOARD_TYPE == 3)
const byte digitMask[] = {0, 1, 2, 3, 4, 5, 6, 7, 8, 9};   // тут вводим свой порядок пинов
const byte opts[] = {KEY0, KEY1, KEY2, KEY3};              // свой порядок индикаторов
const byte cathodeMask[] = {0, 1, 2, 3, 4, 5, 6, 7, 8, 9}; // и свой порядок катодов

#endif

/*
  ард ног ном
  А0  7   4
  А1  6   2
  А2  4   8
  А3  3   1
*/
